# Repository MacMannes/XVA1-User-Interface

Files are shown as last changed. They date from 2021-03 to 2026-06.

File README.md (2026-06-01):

# XVA1 User Interface

A hardware user interface for the [XVA1 virtual analog synthesizer](https://www.futur3soundz.com/), inspired by the Hydrasynth's layout. The XVA1 (and its FM sibling the XFM2) is built on an Artix-7 FPGA but has no built-in UI — this project adds one.

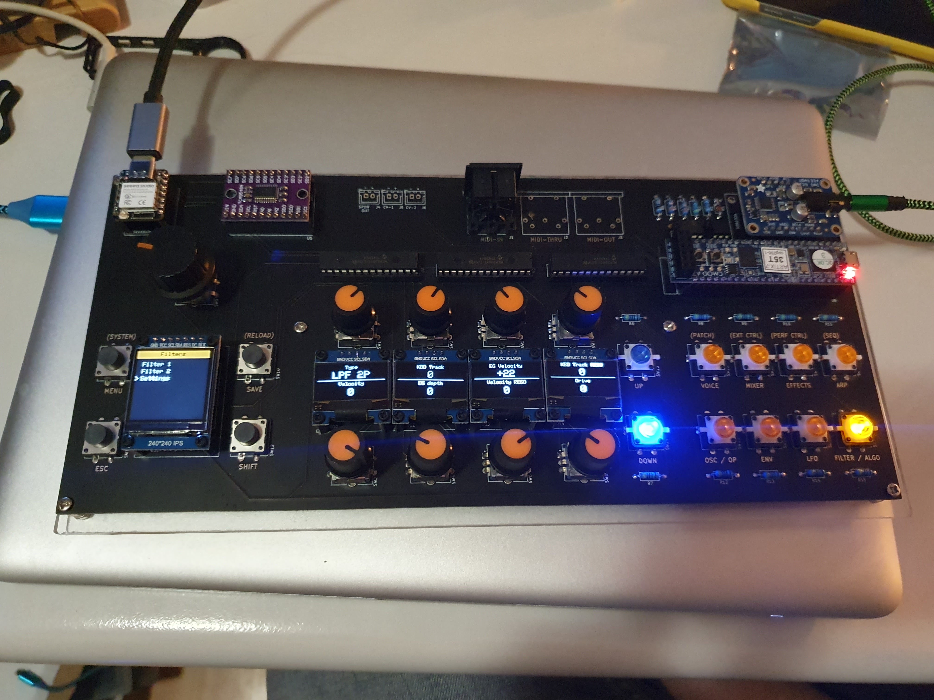
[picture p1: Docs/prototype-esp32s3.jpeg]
XVA1 User Interface prototype


## Overview

The UI board provides:

- **1 main rotary encoder** — patch selection and menu navigation
- **8 parameter rotary encoders** — control up to 8 synth parameters at once
- **4 OLED displays (128×64)** — show parameter names and values for each encoder pair
- **1 TFT display (240×240)** — main display showing patch name, section, and subsection
- **8 shortcut buttons with LEDs** — jump directly to parameter sections (Oscillators, Filters, Envelopes, LFOs, etc.). Hold SHIFT + buttons 1–4 to access sections 9–12
- **Up/Down buttons with LEDs** — scroll through parameter pages within a section

The design goal was minimal menu-diving: select a section with one button press, then tweak up to eight parameters directly with the encoders.

## Hardware

- **MCU:** Seeed XIAO ESP32-S3 (240 MHz, dual-core)
- **IO expansion:** 2× MCP23017 (the 8 parameter encoders connect via I2C)
- **Display mux:** TCA9548A I2C multiplexer for the 4 OLED displays
- **Synth connection:** UART at 500,000 baud (D6 TX, D7 RX)
- **PCB size:** 285 mm × 130 mm
- **Buttons:** PB86-B1 (with LED) / PB86-B0 (without LED), available from AliExpress

KiCad schematics are in the `Hardware/` directory.

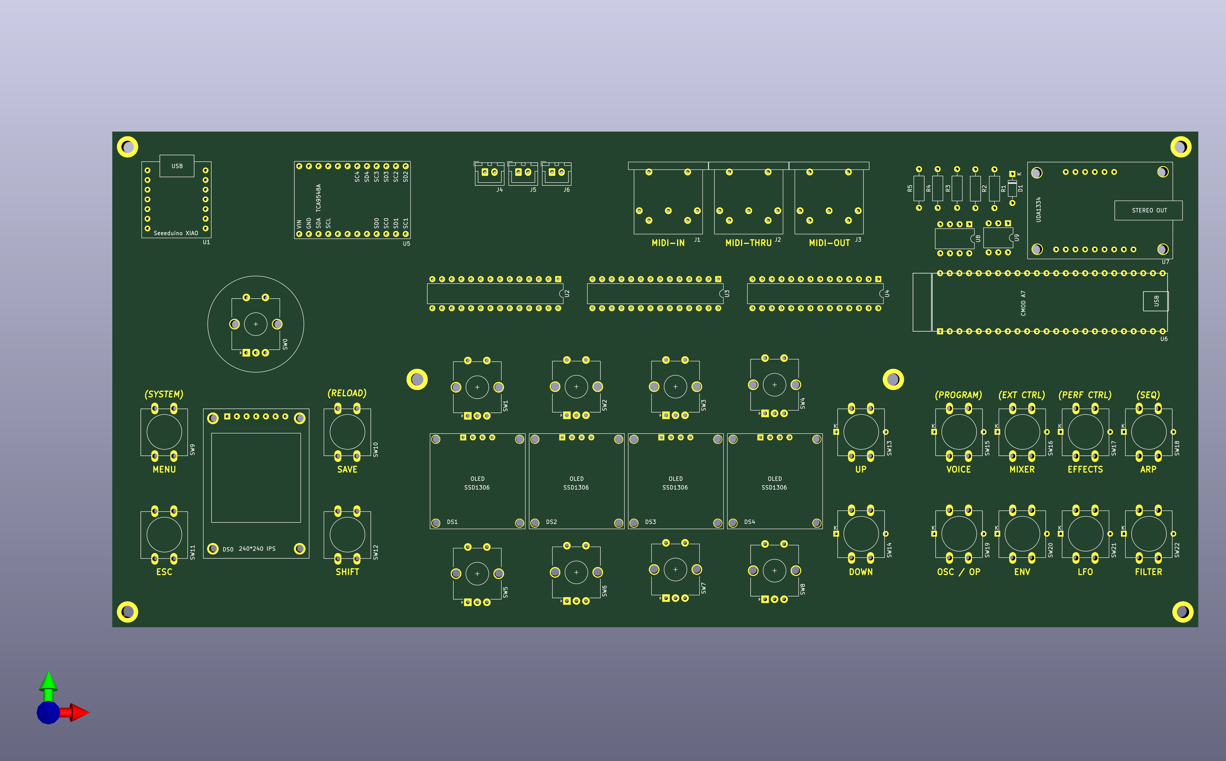
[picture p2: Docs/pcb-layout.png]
PCB layout


## Build History

The project started in early 2021 on a breadboard with a Seeeduino XIAO (SAMD21), then moved to an ESP32 devboard when memory became a bottleneck, and eventually settled on the **Seeed XIAO ESP32-S3** as a drop-in replacement with the same footprint. The first PCB prototype was ordered from JLCPCB and had a few minor errors (MIDI DIN pin swap, resistor silkscreen mix-up) that were corrected in subsequent revisions.

## Software

### UI Board Firmware

Firmware source is in `Software/XVA1UserInterface/` and built with [PlatformIO](https://platformio.org/).

```bash
# Run from Software/XVA1UserInterface/
platformio run                  # compile
platformio run -t upload        # compile and flash
platformio run -t monitor       # open serial monitor (115200 baud)
./upload_and_monitor.sh         # flash then monitor
```

See `AGENTS.md` for a full architecture breakdown and development notes.

### Use in Neovim

In order to use this project in Neovim, you will have to create the file `compile_commands.json`
file by running the following command:

```bash
pio run -t compiledb
```

### Synth Management

To manage the XVA1 (or XFM/XFM2) synthesizer's own firmware and programs, use [**xload-macos**](https://github.com/MacMannes/xload-macos) — a macOS tool for managing flash memory on XFM/XFM2/XVA1 synthesizers.

## Project Structure

```
Hardware/       KiCad schematics and datasheets
Docs/           Photos of front and back of the board
Software/
  XVA1UserInterface/   PlatformIO project (all firmware lives here)
```

## Status

Working prototype. Most parameters are implemented and editable. Patch saving is not yet implemented. The PCB design has gone through two revisions; the current version uses the XIAO ESP32-S3.

## License

See `LICENSE.md`.

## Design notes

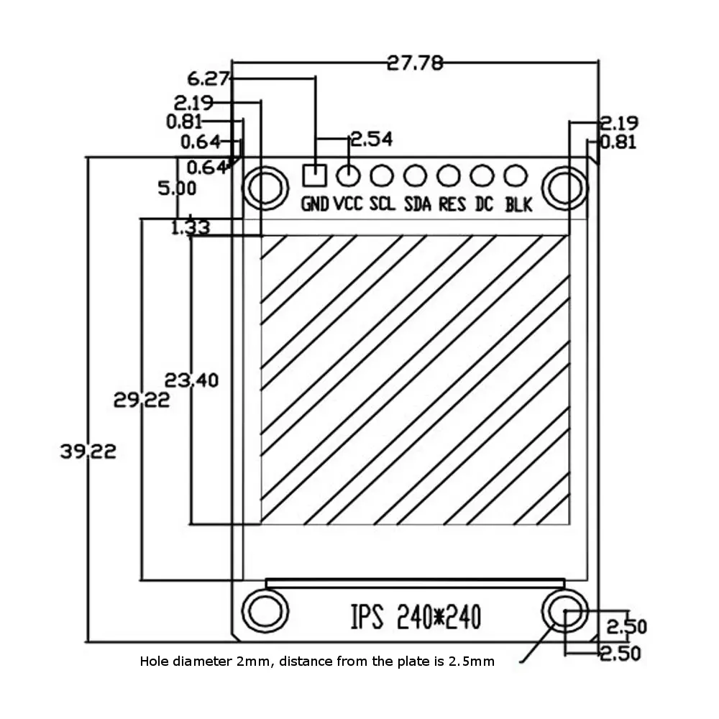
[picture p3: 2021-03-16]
Hardware/Datasheets/tft_st7789.jpg

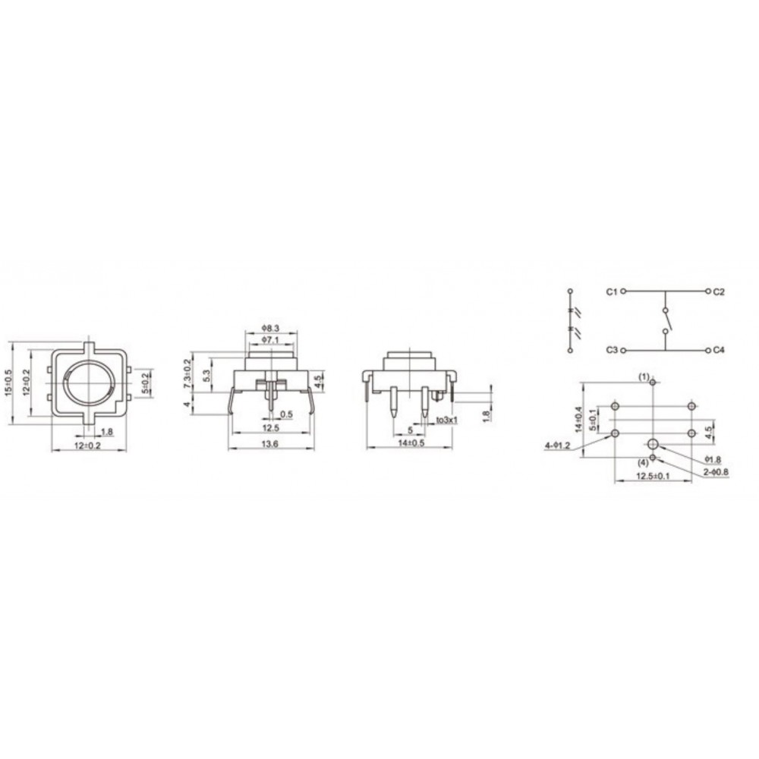
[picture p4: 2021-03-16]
Hardware/Datasheets/btn_led.jpg

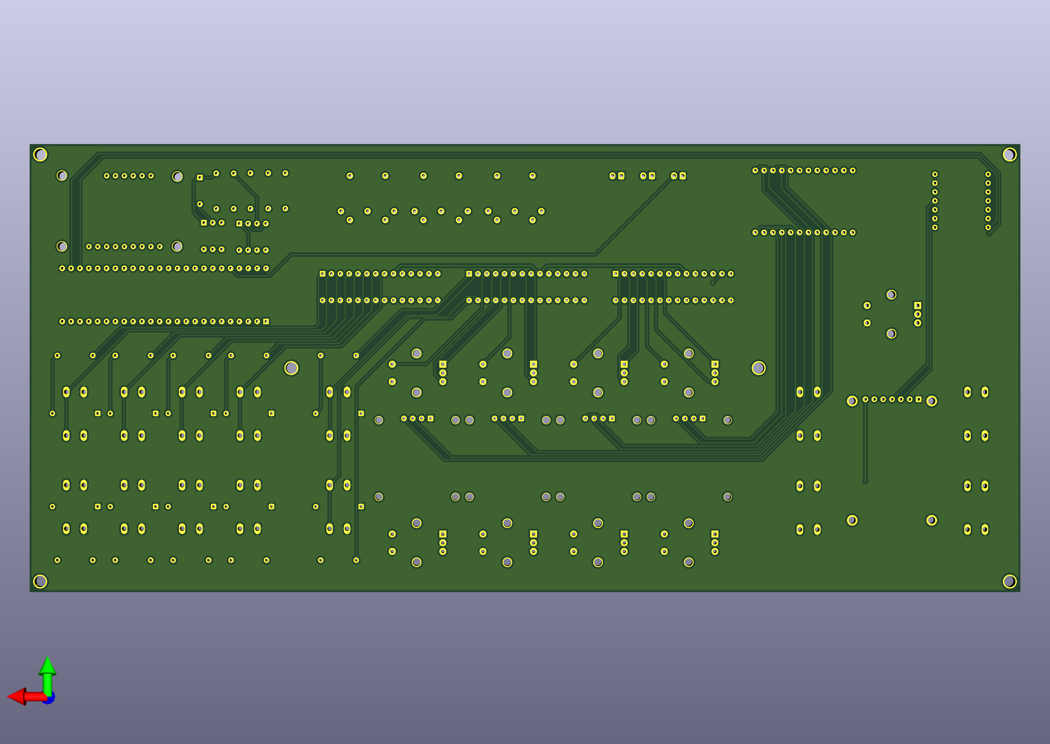
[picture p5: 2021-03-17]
Docs/xva1-ui-back.png

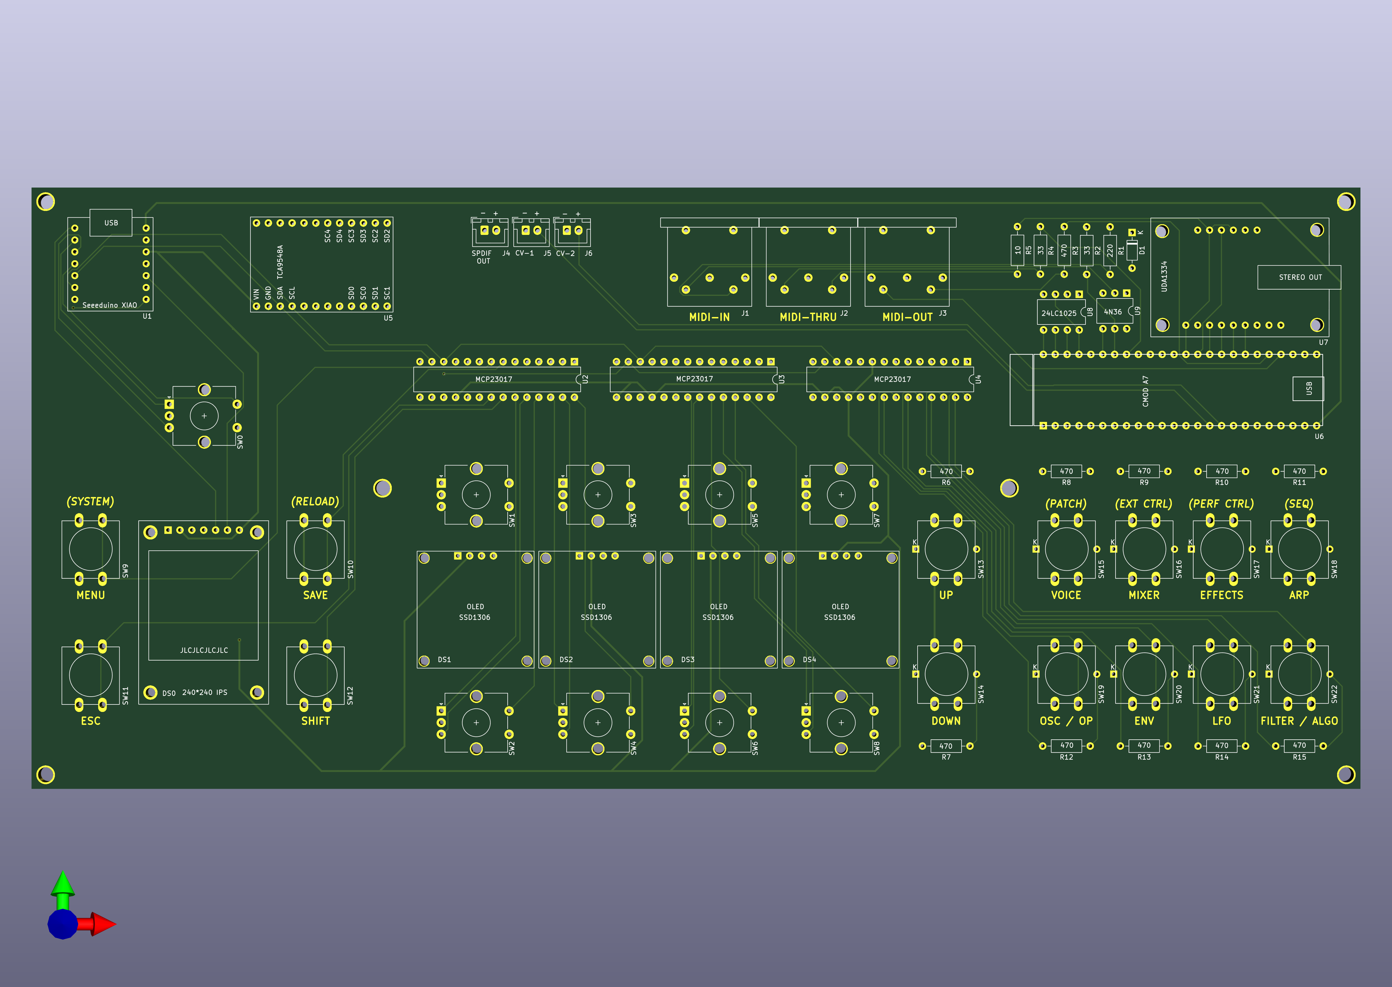
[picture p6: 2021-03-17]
Docs/xva1-ui-front.png

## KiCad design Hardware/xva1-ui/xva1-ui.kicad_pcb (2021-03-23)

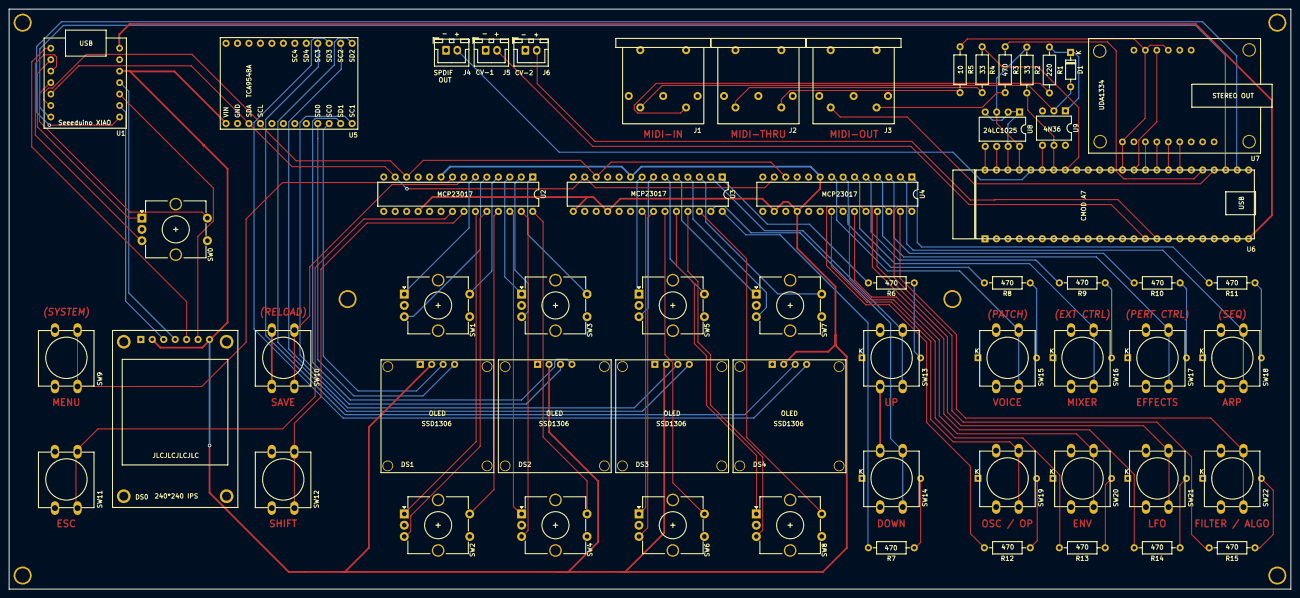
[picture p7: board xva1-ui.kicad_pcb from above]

Board: 2 copper layers, 284.0 x 128.5 mm, 59 parts (0 on the bottom side), 104 nets.

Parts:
D1: 1N4148; D_DO-35_SOD27_P7.62mm_Horizontal
DS0: TFT_ST7789; TFT_IPS-240_240
DS1, DS2, DS3, DS4: SSD1306
J1, J2, J3: DIN-5_180degree; MIDI_CONNECTOR_PCB
J4, J5, J6: Conn_01x02; JST_XH_B2B-XH-A_1x02_P2.50mm_Vertical
R1: 220; R_Axial_DIN0207_L6.3mm_D2.5mm_P10.16mm_Horizontal
R2, R6, R7, R8, R9, R10, R11, R12, R13, R14, R15: 470; R_Axial_DIN0207_L6.3mm_D2.5mm_P10.16mm_Horizontal
R3, R4: 33; R_Axial_DIN0207_L6.3mm_D2.5mm_P10.16mm_Horizontal
R5: 10; R_Axial_DIN0207_L6.3mm_D2.5mm_P10.16mm_Horizontal
SW0, SW1, SW2, SW3, SW4, SW5, SW6, SW7, SW8: Rotary Encoder; RotaryEncoder_Alps_EC12E-Switch_Vertical_H20mm_CircularMoun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
SW9, SW10, SW11, SW12: SW_Push; SW_PUSH-12mm
SW13, SW14, SW15, SW16, SW17, SW18, SW19, SW20, SW21, SW22: SW_Push_LED; SW_PUSH_LED-12mm
U1: Seeeduino XIAO; Seeduino_XIAO_Through-Hole
U2, U3, U4: MCP23017; DIP-28_W7.62mm
U5: TCA9548A; TCA9548A_BREAKOUT
U6: CMOD-A7; CMOD-A7-DIP-48_W15.24mm
U7: UDA1334
U8: 24LC1025-I/P; DIP-8_W7.62mm
U9: 4N36; DIP-6_W7.62mm

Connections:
+3V3: DS0.2, DS0.7, DS1.2, DS2.2, DS3.2, DS4.2, U1.12, U2.9, U2.18, U3.9, U3.15, U3.18, U4.9, U4.16, U4.18, U5.1
+5V: U1.14, U6.24
/BTN-ESC: SW11.2, U2.21
/BTN-MENU: SW9.2, U2.8
/BTN-SAVE: SW10.2, U2.7
/BTN-SHIFT: SW12.2, U2.22
/ENC-A: SW0.A, U1.2
/ENC-B: SW0.B, U1.3
/ENC-S: SW0.S1, U1.4
/SCL: U1.6, U2.12, U3.12, U4.12, U5.4
/SDA: U1.5, U2.13, U3.13, U4.13, U5.3
BTN-DWN: SW14.2, U3.27
BTN-SC1: SW15.2, U4.8
BTN-SC2: SW16.2, U4.6
BTN-SC3: SW17.2, U4.4
BTN-SC4: SW18.2, U4.2
BTN-SC5: SW19.2, U4.21
BTN-SC6: SW20.2, U4.23
BTN-SC7: SW21.2, U4.25
BTN-SC8: SW22.2, U4.27
BTN-UP: SW13.2, U3.2
CV-INPUT-1: J5.2, U6.15
CV-INPUT-2: J6.2, U6.16
ENC1-A: SW1.A, U2.6
ENC1-B: SW1.B, U2.5
ENC1-S: SW1.S1, U2.4
ENC2-A: SW2.A, U2.23
ENC2-B: SW2.B, U2.24
ENC2-S: SW2.S1, U2.25
ENC3-A: SW3.A, U2.3
ENC3-B: SW3.B, U2.2
ENC3-S: SW3.S1, U2.1
ENC4-A: SW4.A, U2.26
ENC4-B: SW4.B, U2.27
ENC4-S: SW4.S1, U2.28
ENC5-A: SW5.A, U3.8
ENC5-B: SW5.B, U3.7
ENC5-S: SW5.S1, U3.6
ENC6-A: SW6.A, U3.21
ENC6-B: SW6.B, U3.22
ENC6-S: SW6.S1, U3.23
ENC7-A: SW7.A, U3.5
ENC7-B: SW7.B, U3.4
ENC7-S: SW7.S1, U3.3
ENC8-A: SW8.A, U3.24
ENC8-B: SW8.B, U3.25
ENC8-S: SW8.S1, U3.26
GND: DS0.1, DS1.1, DS2.1, DS3.1, DS4.1, J4.1, J5.1, J6.1, SW0.C, SW0.S2, SW1.C, SW1.S2, SW2.C, SW2.S2, SW3.C, SW3.S2, SW4.C, SW4.S2, SW5.C, SW5.S2, SW6.C, SW6.S2, SW7.C, SW7.S2, SW8.C, SW8.S2, SW9.1, SW10.1, SW11.1, SW12.1, SW13.1, SW13.3, SW14.1, SW14.3, SW15.1, SW15.3, SW16.1, SW16.3, SW17.1, SW17.3, SW18.1, SW18.3, SW19.1, SW19.3, SW20.1, SW20.3, SW21.1, SW21.3, SW22.1, SW22.3, U1.13, U2.10, U2.15, U2.16, U2.17, U3.10, U3.16, U3.17, U4.10, U4.15, U4.17, U5.2, U6.25
LED-DWN: R7.2, U3.28
LED-SC1: R8.2, U4.7
LED-SC2: R9.2, U4.5
LED-SC3: R10.2, U4.3
LED-SC4: R11.2, U4.1
LED-SC5: R12.2, U4.22
LED-SC6: R13.2, U4.24
LED-SC7: R14.2, U4.26
LED-SC8: R15.2, U4.28
LED-UP: R6.2, U3.1
unnamed: D1.1, R1.1, U9.1
unnamed: D1.2, J1.5, U9.2
unnamed: DS0.3, U1.9
unnamed: DS0.4, U1.11
unnamed: DS0.5, U1.1
unnamed: DS0.6, U1.10
unnamed: J1.4, R1.2
unnamed: J2.4, R5.1
unnamed: J2.5, R4.1
unnamed: J3.4, R3.1
unnamed: J3.5, U6.28
unnamed: R2.1, U6.45, U8.3, U8.8
unnamed: R2.2, U6.42, U9.5
unnamed: R3.2, U6.29
unnamed: R4.2, U6.41
unnamed: R5.2, U6.36, U7.1, U7.12, U7.14
unnamed: R6.1, SW13.4
unnamed: R7.1, SW14.4
unnamed: R8.1, SW15.4
unnamed: R9.1, SW16.4
unnamed: R10.1, SW17.4
unnamed: R11.1, SW18.4
unnamed: R12.1, SW19.4
unnamed: R13.1, SW20.4
unnamed: R14.1, SW21.4
unnamed: R15.1, SW22.4
unnamed: U6.31, U7.6
unnamed: U6.32, U7.5
unnamed: U6.33, U7.4
unnamed: U6.34, U7.3
unnamed: U6.35, U7.13
unnamed: U6.43, U9.4
unnamed: U6.46, U8.1, U8.2, U8.4, U8.7
unnamed: U6.47, U8.6
unnamed: U6.48, U8.5
OLED1-SCL: DS1.3, U5.10
OLED1-SDA: DS1.4, U5.9
OLED2-SCL: DS2.3, U5.12
OLED2-SDA: DS2.4, U5.11
OLED3-SCL: DS3.3, U5.14
OLED3-SDA: DS3.4, U5.13
OLED4-SCL: DS4.3, U5.16
OLED4-SDA: DS4.4, U5.15
SPDIF-OUT: J4.2, U6.44
XIAO-RX: U1.8, U6.26
XIAO-TX: U1.7, U6.27

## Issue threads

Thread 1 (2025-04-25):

MIDI performance control bug

craigyjp, 2025-04-25:
I hope you don’t mind me mentioning a bug in your code when editing MIDI perf controls, these are supposed to be editable between 1-511 to cover all parameters of the synth, but your code only allows you to edit them from 0-255 due to using a byte rather than an integer for definition.

Currently you display 257 as a value for one of the MIDI performance controllers, but you cannot increment that, only decrement it, then once it is 255 it will not go any higher.

Also I added the range limit of 1-511 as 0 is not available as that is not a valid parameter in the synth.

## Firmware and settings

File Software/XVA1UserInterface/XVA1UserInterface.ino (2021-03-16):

/*
    XVA1 User Interface
*/

#include <SPI.h>
#include <TFT_eSPI.h>
#include <Wire.h>
#include <Adafruit_GFX.h>
#include <Adafruit_SSD1306.h>
#include <splash.h>
#include "RotaryEncOverMCP.h"
#include "Rotary.h"
#include "SynthParameter.h"

#define MUX_ADDRESS 0x70 // TCA9548A Multiplexer address

#define SCREEN_WIDTH 128 // OLED display width, in pixels
#define SCREEN_HEIGHT 64 // OLED display height, in pixels
#define LOGO_HEIGHT   16
#define LOGO_WIDTH    16

#define SHIFT_BTN_PIN 8
#define SHORTCUT_BTN1_PIN 9
#define SHORTCUT_LED1_PIN 10

#define ROTARY_BTN1_PIN 2
#define ROTARY_BTN2_PIN 5

int allButtons[] = { SHIFT_BTN_PIN, SHORTCUT_BTN1_PIN, ROTARY_BTN1_PIN, ROTARY_BTN2_PIN};
constexpr int numButtons = (int)(sizeof(allButtons) / sizeof(*allButtons));


/* First I2C MCP23017 GPIO expanders */
Adafruit_MCP23017 mcp1;  

//Array of pointers of all MCPs (for now, there's only 1)
Adafruit_MCP23017* allMCPs[] = { &mcp1 };
constexpr int numMCPs = (int)(sizeof(allMCPs) / sizeof(*allMCPs));

/* function prototypes */
void rotaryEncoderChanged(bool clockwise, int id);

/* Array of all rotary encoders and their pins */
RotaryEncOverMCP rotaryEncoders[] = {
        // outputA,B on GPA7,GPA6, register with callback and ID=1
        RotaryEncOverMCP(&mcp1, 7, 6, &rotaryEncoderChanged, 0),
        RotaryEncOverMCP(&mcp1, 1, 0, &rotaryEncoderChanged, 1),
        RotaryEncOverMCP(&mcp1, 4, 3, &rotaryEncoderChanged, 2)
};
constexpr int numEncoders = (int)(sizeof(rotaryEncoders) / sizeof(*rotaryEncoders));

// Initialize I2C buses using TCA9548A I2C Multiplexer
void selectMultiplexerChannel(uint8_t i2c_bus) {
    if (i2c_bus > 7) return;
    Wire.beginTransmission(MUX_ADDRESS);
    Wire.write(1 << i2c_bus);
    Wire.endTransmission(); 
}

// Declaration for an SSD1306 display connected to I2C (SDA, SCL pins)
#define OLED_RESET     -1 // Reset pin # (or -1 if sharing Arduino reset pin)
Adafruit_SSD1306 display(SCREEN_WIDTH, SCREEN_HEIGHT, &Wire, OLED_RESET);

const int MAX = 128;
const int MIN = 1;
int currentPatchNumber = MIN;
String currentPatchName = "";
byte currentPatchData[512];

TFT_eSPI tft = TFT_eSPI();  // Invoke library, pins defined in User_Setup.h

#define TFT_GREY 0x5AEB // New colour

struct SynthParameter param1;
struct SynthParameter param2;
struct SynthParameter param3;
struct SynthParameter param4;

unsigned long lastTransition;
unsigned long revolutionTime = 0;

bool shiftButtonPushed = false;
int shortcutButtonState = HIGH;
bool shortcut1Active = false;

void rotaryEncoderChanged(bool clockwise, int id) {
    unsigned long now = millis();
    revolutionTime = now - lastTransition;    

    int speed = 1;
    if (revolutionTime < 50) {
        speed = 20;
    } else if (revolutionTime < 125) {
        speed = 10;
    } else if (revolutionTime < 250) {
        speed = 2;
    } 

    lastTransition = now;
  
    Serial.println("Encoder " + String(id) + ": "
            + (clockwise ? String("clockwise") : String("counter-clock-wise")) + ", Speed: " + String(speed));
    if (id == 0) {
       handleMainEncoder(clockwise);
    }
    if (shiftButtonPushed) {
      if (id == 1) {
          handleParameterChange(&param3, clockwise, speed);
          displayTwinParameters(&param3, &param4, 1);
      }
      if (id == 2) {
          handleParameterChange(&param4, clockwise, speed);
          displayTwinParameters(&param3, &param4, 1);
      }
    } else {
      if (id == 1) {
          handleParameterChange(&param1, clockwise, speed);
          displayTwinParameters(&param1, &param2, 0);
      }
      if (id == 2) {
          handleParameterChange(&param2, clockwise, speed);
          displayTwinParameters(&param1, &param2, 0);
      }
    }
}


void setup() {
    SerialUSB.begin(115200);

     //while the serial stream is not open, do nothing:
//     while (!Serial);   

//    strcpy(param1.name, "FilterType");
//    param1.number = 71;
//    param1.min = 0;
//    param1.max = 21;
//    param1.descriptions[0] = "Bypass";
//    param1.descriptions[1] = "1P_LowPass";
//    param1.descriptions[2] = "2P_LowPass";
//    param1.descriptions[3] = "3P_LowPass";
//    param1.descriptions[4] = "4P_LowPass";
//    param1.descriptions[5] = "1P_HighPass";
//    param1.descriptions[6] = "2P_HighPass";
//    param1.descriptions[7] = "3P_HighPass";
//    param1.descriptions[8] = "4P_HighPass";


    strcpy(param1.name, "Sequencer");
    param1.number = 428;
    param1.min = 0;
    param1.max = 1;    
    param1.descriptions[0] = "OFF";
    param1.descriptions[1] = "ON";
    
    strcpy(param2.name, "Cutoff");
    param2.number = 72;
    param2.min = 0;
    param2.max = 255;

    strcpy(param3.name, "PerfCtl1");
    param3.type = PERFORMANCE_CTRL;
    param3.number = 400;
    param3.number2 = 401;
    param3.min = 0;
    param3.max = 511;

    strcpy(param4.name, "PerfCtl2");
    param4.type = PERFORMANCE_CTRL;
    param4.number = 402;
    param4.number2 = 403;   
    param4.min = 0;
    param4.max = 511;

//    strcpy(param1.name, "ARP_MODE");
//    param1.number = 450;
//    param1.min = 0;
//    param1.max = 5;    
//    strcpy(param2.name, "Octaves");
//    param2.number = 454;
//    param2.min = 0;
//    param2.max = 5;
    
  
    mcp1.begin();      // use default address 0
    // Initialize input encoders (pin mode, interrupt)
    for(int i=0; i < numEncoders; i++) {
        rotaryEncoders[i].init();
    }

    initOledDisplays();
    initButtons();
    
    Serial1.begin(500000); // XVA1 Serial
  
    tft.init();
    tft.setRotation(0);  // 0 & 2 Portrait. 1 & 3 landscapeooooooo;;
    tft.fillScreen(TFT_BLACK);
  
    tft.setCursor(0, 0, 2);
    // Set the font colour to be white with a black background, set text size multiplier to 1
    tft.setTextColor(TFT_WHITE,TFT_BLACK);  
    tft.setTextSize(1);
    tft.println("XVA1 Synthesizer");  
    
  
    
    SerialUSB.println("\n");
    SerialUSB.println("===================");
    SerialUSB.println("XVA1 User Interface");
    SerialUSB.println("===================\n");
    SerialUSB.print("value=");
    SerialUSB.println(currentPatchNumber);
  
    selectPatchOnSynth(currentPatchNumber);
    getPatchDataFromSynth();
    displayPatchInfo();

}

void loop() {
    pollAllMCPs();
    readButtons();    
}


void initOledDisplays() {
    for (int d = 0; d < 2; d++) {
      selectMultiplexerChannel(d);
      // SSD1306_SWITCHCAPVCC = generate display voltage from 3.3V internally
      display.begin(SSD1306_SWITCHCAPVCC, 0x3C);
    
      display.clearDisplay();
    }  
}

void initButtons() {
  for (int i = 0; i < numButtons; i++) {
      int pin = allButtons[i];
      mcp1.pinMode(pin, INPUT);   // Button i/p to GND
      mcp1.pullUp(pin, HIGH);     // Pulled high ~100k    
  }
  
//  mcp1.pinMode(SHIFT_BTN_PIN, INPUT);   // Button i/p to GND
//  mcp1.pullUp(SHIFT_BTN_PIN, HIGH);     // Pulled high ~100k


  mcp1.pinMode(SHORTCUT_LED1_PIN, OUTPUT);   // LED from Shortcut button 1
  
}

void readButtons() {
    bool shiftButton = mcp1.digitalRead(SHIFT_BTN_PIN) == LOW;
    if (shiftButton != shiftButtonPushed) {
      shiftButtonPushed = shiftButton;
      SerialUSB.print("Shift: ");
      SerialUSB.println(shiftButtonPushed);
    }
    

    int shortcutButton1 = mcp1.digitalRead(SHORTCUT_BTN1_PIN);
    if (shortcutButton1 != shortcutButtonState) {
      shortcutButtonState = shortcutButton1;
      SerialUSB.print("Shortcut 1: ");
      SerialUSB.println(shortcutButton1 == LOW);

      if (shortcutButton1 == HIGH) {
        // Button released, toggle LED        
        shortcut1Active = !shortcut1Active;
        mcp1.digitalWrite(SHORTCUT_LED1_PIN, shortcut1Active ? HIGH : LOW);
      }
    }
    
}

void handleMainEncoder(bool clockwise) {
    int oldValue = currentPatchNumber;

    if (clockwise) {
      if (currentPatchNumber < MAX) {
        currentPatchNumber++;
      }
    } else {
      if (currentPatchNumber > MIN) {
        currentPatchNumber--;
      }        
    }

    SerialUSB.print("Selecting patch: ");
    SerialUSB.println(currentPatchNumber);

    if (currentPatchNumber != oldValue) {
       selectPatchOnSynth(currentPatchNumber);
       getPatchDataFromSynth();
       displayPatchInfo();
    }
}

void selectPatchOnSynth(int patchNumber) {
    int synthPatchNumber = patchNumber - 1;
    
    SerialUSB.print("Selecting patch #");
    SerialUSB.print(synthPatchNumber);
    SerialUSB.print(" on Synth...");
    
    Serial1.write('r'); // 'r' = Read program
    Serial1.write(synthPatchNumber);
  
  
    int read_status;
    int bytesRead = 0;
    int retry = 0;
    while (bytesRead == 0 && retry != 100) {
      if (Serial1.available()) {
          read_status = Serial1.read();
          bytesRead++;
          retry = 0;
      } else {
        retry++;
        delay(10);
      }
    }  
  
    SerialUSB.print("Status=");
    SerialUSB.println(read_status, DEC);  

}

void getPatchDataFromSynth() {

    Serial1.write('d'); // 'd' = Display program

    SerialUSB.println("Reading patch data from Synth...");

    byte rxBuffer[512];
    int bytesRead = 0;
    int retry = 0;
    while (bytesRead != 512 && retry != 100) {
      if (Serial1.available()) {
          byte b = Serial1.read();
          rxBuffer[bytesRead] = b;
          bytesRead++;
          retry = 0;
      } else {
        retry++;
        delay(10);
      }
    }
    
//    for (int i = 0; i < sizeof(rxBuffer); i++){
//      printHex(rxBuffer[i]);
//    }
  
    SerialUSB.println();

    String patchName = "";
 
    for (int i=480; i<505; i++){
      patchName += (char)rxBuffer[i];
    }      

    SerialUSB.print("Patch name: ");
    SerialUSB.println(patchName);
    SerialUSB.println(); 
    
    Serial1.flush();

    memcpy(currentPatchData, rxBuffer, 512);
    currentPatchName = patchName; 
}

void displayPatchInfo() {
//  tft.setTextSize(2);
    tft.setTextColor(TFT_WHITE, TFT_BLACK);   
    tft.drawString("Patch", 0, 30, 1);
    
    tft.setTextColor(TFT_YELLOW, TFT_BLACK);   
  
    // Set the padding to the maximum width that the digits could occupy in font 4
    // This ensures small numbers obliterate large ones on the screen
    tft.setTextPadding(tft.textWidth("999", 4) );  
    // Draw the patch number in font 4
    tft.drawNumber(currentPatchNumber, 0, 42, 4);
  
    tft.setTextColor(TFT_RED, TFT_BLACK); 
  
    tft.setTextPadding(tft.textWidth("XXXXXXXXXXXXXXXXXXXXXXXXX", 2) );  
    // Draw the patch name in font 1
    tft.drawString(currentPatchName, 0, 75, 2);
  
    // Reset text padding to 0 otherwise all future rendered strings will use it!
    tft.setTextPadding(0);
  
    displayTwinParameters(&param1, &param2, 0);
    displayTwinParameters(&param3, &param4, 1);

}

void drawCenteredText(char *buf, int x, int y)
{
    int16_t x1, y1;
    uint16_t w, h;
    display.getTextBounds(buf, x, y, &x1, &y1, &w, &h); //calc width of new string
    display.setCursor(x - w / 2, y);
    display.print(buf);
}

void printHex(uint8_t num) {
    char hexCar[2];
  
    sprintf(hexCar, "%02X", num);
    SerialUSB.print(hexCar);
  }

void pollAllMCPs() {
    //We could also call ".poll()" on each encoder,
    //however that will cause an I2C transfer
    //for every encoder.
    //It's faster to only go through each MCP object,
    //read it, and then feed it into the encoder as input.
    for(int j = 0; j < numMCPs; j++) {
        uint16_t gpioAB = allMCPs[j]->readGPIOAB();
        for (int i=0; i < numEncoders; i++) {
            //only feed this in the encoder if this
            //is coming from the correct MCP
            if(rotaryEncoders[i].getMCP() == allMCPs[j])
                rotaryEncoders[i].feedInput(gpioAB);
        }
    }
}

void displayTwinParameters(SynthParameter *param1, SynthParameter *param2, int displayNumber) {  
    int byte1;
    int byte2;

    if (param1->type == PERFORMANCE_CTRL) {
      byte msb = currentPatchData[param1->number]; 
      byte lsb = currentPatchData[param1->number2]; 
      int combined = (msb << 7) + lsb;

      byte1 = (int)combined;      
    } else {
      byte1 = (int)currentPatchData[param1->number];      
    }    

    if (param2->type == PERFORMANCE_CTRL) {
      byte msb = currentPatchData[param2->number]; 
      byte lsb = currentPatchData[param2->number2]; 
      int combined = (msb << 7) + lsb;

      byte2 = (int)combined;      
    } else {
      byte2 = (int)currentPatchData[param2->number];      
    }    
    
    char printValue1[20];
    if (param1->type != PERFORMANCE_CTRL && byte1 < sizeof(param1->descriptions) && param1->descriptions[byte1] != nullptr) {
      strcpy(printValue1, param1->descriptions[byte1]);    
    } else {
      sprintf(printValue1,"%ld", byte1);
    }
    char printValue2[20];
    if (param2->type != PERFORMANCE_CTRL && byte2 < sizeof(param2->descriptions) && param2->descriptions[byte1] != nullptr) {
      strcpy(printValue2, param2->descriptions[byte2]);    
    } else {
      sprintf(printValue2,"%ld", byte2);
    }
  
    displayTwinParameters(param1->name, printValue1, param2->name, printValue2, displayNumber);
}

void displayTwinParameters(char *title1, char *value1, char *title2, char *value2, int displayNumber) {
    selectMultiplexerChannel(displayNumber);

    display.clearDisplay();  
    
    display.setTextSize(1);
    display.setTextColor(WHITE);
    drawCenteredText(title1, 64, 0);
  
    display.setTextSize(2);
    drawCenteredText(value1, 64, 12);
  
    display.drawLine(0, 30, display.width() - 1, 30, WHITE);
  
    
    display.setTextSize(1);
    drawCenteredText(title2, 64, 34);
  
    display.setTextSize(2);
    drawCenteredText(value2, 64, 47);
    
    display.display(); 
}

void handleParameterChange(SynthParameter *param, bool clockwise, int speed) {
    int currentValue;

    if (param->type == PERFORMANCE_CTRL) {
      byte msb = currentPatchData[param->number]; 
      byte lsb = currentPatchData[param->number2]; 
      int combined = (msb << 7) + lsb;
      currentValue = combined;
    } else {    
      currentValue = currentPatchData[param->number];
    }
    int newValue = -1;
  
    if (clockwise) {
        if (currentValue < param->max) {
            newValue = currentValue + speed;
            if  (newValue > param->max) {
                newValue = param->max;
            }
        }
    } else {
        if (currentValue > param->min) {
          newValue = currentValue - speed;
            if  (newValue < param->min) {
                newValue = param->min;
            }
        }
    }

  
    if (newValue >= 0 && newValue != currentValue) {
        SerialUSB.print("New value: ");
        SerialUSB.println(newValue);
        if (param->type == PERFORMANCE_CTRL) {
          byte msb = newValue >> 7;
          byte lsb = newValue & 127;

          currentPatchData[param->number] = msb;
          currentPatchData[param->number2] = lsb;

          setParameter(param->number, msb);
          setParameter(param->number2, lsb);          
        } else {
          currentPatchData[param->number] = newValue;
    
          setParameter(param->number, newValue);
        }
    }
  
}


void setParameter(int param, int value) {
    Serial1.write('s'); // 's' = Set Parameter

    if (param > 255) {
        // Parameters above 255 have a two-byte format: b1 = 255, b2 = x-256
        Serial1.write(255);
        Serial1.write(param - 256 );
        Serial1.write(value);
    } else {
        Serial1.write(param);
        Serial1.write(value);
    }
}

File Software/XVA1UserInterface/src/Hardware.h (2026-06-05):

//
// Created by André Mathlener on 05/04/2021.
//

#ifndef XVA1USERINTERFACE_HARDWARE_H
#define XVA1USERINTERFACE_HARDWARE_H

#include <Rotary.h>
#include <RotaryEncOverMCP.h>

#include "Button.h"
#include "Multiplexer.h"
#include "ParameterController.h"
#include "Synthesizer.h"

#define MAIN_ROTARY_BUTTON 0
#define MENU_BUTTON        1
#define SAVE_BUTTON        2
#define ESC_BUTTON         3
#define SHIFT_BUTTON       4

#define UP_BUTTON   1
#define DOWN_BUTTON 2

#define SCREEN_WIDTH  128  // OLED display width, in pixels
#define SCREEN_HEIGHT 64   // OLED display height, in pixels

// Declaration for an SSD1306 display connected to I2C (SDA, SCL pins)
#define OLED_RESET (-1)  // Reset pin # (or -1 if sharing Arduino reset pin)

#define MAIN_ROTARY_BTN_PIN D3

// Pins for MCP23017
#define GPA0 0
#define GPA1 1
#define GPA2 2
#define GPA3 3
#define GPA4 4
#define GPA5 5
#define GPA6 6
#define GPA7 7
#define GPB0 8
#define GPB1 9
#define GPB2 10
#define GPB3 11
#define GPB4 12
#define GPB5 13
#define GPB6 14
#define GPB7 15

/* Function prototypes */

void mainRotaryButtonChanged(bool released);

void mainButtonChanged(Button* btn, bool released);

void shortcutButtonChanged(Button* btn, bool released);

void rotaryButtonChanged(Button* btn, bool released);

void upOrDownButtonChanged(Button* btn, bool released);

void rotaryEncoderChanged(bool clockwise, int id);

// TCA9548A Multiplexer
Multiplexer multiplexer = Multiplexer(0x70);

// I2C MCP23017 GPIO expanders
Adafruit_MCP23017 mcp1;
Adafruit_MCP23017 mcp2;
Adafruit_MCP23017 mcp3;

// Array of pointers of all MCPs
Adafruit_MCP23017* allMCPs [] = { &mcp1, &mcp2, &mcp3 };

// OLED display
Adafruit_SSD1306 display(SCREEN_WIDTH, SCREEN_HEIGHT, &Wire, OLED_RESET);

// TFT display
TFT_eSPI tft = TFT_eSPI();  // Invoke library, pins defined in User_Setup.h

Rotary mainRotaryEncoder = Rotary(D1, D2);

/* Array of all rotary encoders and their pins */
RotaryEncOverMCP rotaryEncoders [] = {
    // outputA,B on GPA7,GPA6, register with callback and ID=1
    RotaryEncOverMCP(&mcp1, GPB5, GPB4, &rotaryEncoderChanged, 1),
    RotaryEncOverMCP(&mcp1, GPA2, GPA3, &rotaryEncoderChanged, 2),
    RotaryEncOverMCP(&mcp1, GPB2, GPB1, &rotaryEncoderChanged, 3),
    RotaryEncOverMCP(&mcp1, GPA5, GPA6, &rotaryEncoderChanged, 4),
    RotaryEncOverMCP(&mcp2, GPB7, GPB6, &rotaryEncoderChanged, 5),
    RotaryEncOverMCP(&mcp2, GPA0, GPA1, &rotaryEncoderChanged, 6),
    RotaryEncOverMCP(&mcp2, GPB4, GPB3, &rotaryEncoderChanged, 7),
    RotaryEncOverMCP(&mcp2, GPA3, GPA4, &rotaryEncoderChanged, 8),
};

Button menuButton = Button(&mcp1, GPB7, MENU_BUTTON, &mainButtonChanged);
Button saveButton = Button(&mcp1, GPB6, SAVE_BUTTON, &mainButtonChanged);
Button escButton = Button(&mcp1, GPA0, ESC_BUTTON, &mainButtonChanged);
Button shiftButton = Button(&mcp1, GPA1, SHIFT_BUTTON, &mainButtonChanged);

Button* mainButtons [] = {
    &menuButton,
    &saveButton,
    &escButton,
    &shiftButton,
};

LEDButton shortcutButton1 =
    LEDButton(&mcp3, GPB7, GPB6, 1, &shortcutButtonChanged);
LEDButton shortcutButton2 =
    LEDButton(&mcp3, GPB5, GPB4, 2, &shortcutButtonChanged);
LEDButton shortcutButton3 =
    LEDButton(&mcp3, GPB3, GPB2, 3, &shortcutButtonChanged);
LEDButton shortcutButton4 =
    LEDButton(&mcp3, GPB1, GPB0, 4, &shortcutButtonChanged);
LEDButton shortcutButton5 =
    LEDButton(&mcp3, GPA0, GPA1, 5, &shortcutButtonChanged);
LEDButton shortcutButton6 =
    LEDButton(&mcp3, GPA2, GPA3, 6, &shortcutButtonChanged);
LEDButton shortcutButton7 =
    LEDButton(&mcp3, GPA4, GPA5, 7, &shortcutButtonChanged);
LEDButton shortcutButton8 =
    LEDButton(&mcp3, GPA6, GPA7, 8, &shortcutButtonChanged);

LEDButton* shortcutButtons [] = { &shortcutButton1, &shortcutButton2,
                                  &shortcutButton3, &shortcutButton4,
                                  &shortcutButton5, &shortcutButton6,
                                  &shortcutButton7, &shortcutButton8 };

Button rotaryButton1 = Button(&mcp1, GPB3, 1, &rotaryButtonChanged);
Button rotaryButton2 = Button(&mcp1, GPA4, 2, &rotaryButtonChanged);
Button rotaryButton3 = Button(&mcp1, GPB0, 3, &rotaryButtonChanged);
Button rotaryButton4 = Button(&mcp1, GPA7, 4, &rotaryButtonChanged);
Button rotaryButton5 = Button(&mcp2, GPB5, 5, &rotaryButtonChanged);
Button rotaryButton6 = Button(&mcp2, GPA2, 6, &rotaryButtonChanged);
Button rotaryButton7 = Button(&mcp2, GPB2, 7, &rotaryButtonChanged);
Button rotaryButton8 = Button(&mcp2, GPA5, 8, &rotaryButtonChanged);

LEDButton upButton = LEDButton(&mcp2, GPB1, GPB0, 1, &upOrDownButtonChanged);
LEDButton downButton = LEDButton(&mcp2, GPA6, GPA7, 2, &upOrDownButtonChanged);
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

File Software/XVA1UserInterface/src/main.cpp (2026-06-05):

#include <Adafruit_I2CDevice.h>
#include <Adafruit_SSD1306.h>
#include <Arduino.h>
#include <TFT_eSPI.h>
#include <Wire.h>

#include "Button.h"
#include "Debug.h"
#include "FreeMemory.h"
#include "Globals.h"
#include "Hardware.h"
#include "SynthParameter.h"

unsigned long lastTransition;
unsigned long revolutionTime = 0;

int activeShortcut = 0;

bool shiftButtonPushed = false;
bool mainRotaryButtonPushed = false;

/* function prototypes */

void handleMainEncoder(bool clockwise);

void initOLEDDisplays();

void pollAllMCPs();

void readButtons();

void displayPatchInfo();

void displayPatchInfo(bool paintItBlack);

void initButtons();

void clearShortcut();

void clearMainScreen();

void initMainScreen();

void initRotaryEncoders();

void rtrim(std::string& s, char c);

void setup() {
    LOG_BEGIN();

    LOGLN("\n");
    LOGLN("===================");
    LOGLN("XVA1 User Interface");
    LOGLN("===================\n");

    mcp1.begin(0);
    mcp2.begin(1);
    mcp3.begin(2);

    synthesizer.begin();

    initMainScreen();
    clearMainScreen();

    initRotaryEncoders();
    initOLEDDisplays();
    initButtons();

    synthesizer.selectPatch(4);
    parameterController.setDefaultSection();
    displayPatchInfo();

    mainRotaryEncoder.begin(true);

    LOG("freeMemory()=");
    LOGLN(freeMemory());
}

void loop() {
    unsigned char result = mainRotaryEncoder.process();
    if (result) {
        bool clockwise = result == DIR_CW;
        if (activeShortcut != 0) {
            bool consumed =
                parameterController.rotaryEncoderChanged(0, clockwise, 1);
            if (!consumed) {
                handleMainEncoder(clockwise);
            }
        } else {
            handleMainEncoder(clockwise);
        }
    }

    readButtons();
    pollAllMCPs();
}

void rotaryEncoderChanged(bool clockwise, int id) {
    unsigned long now = millis();
    revolutionTime = now - lastTransition;

    int speed = 1;
    if (revolutionTime < 50) {
        speed = 20;
    } else if (revolutionTime < 125) {
        speed = 10;
    } else if (revolutionTime < 250) {
        speed = 2;
    }

    lastTransition = now;

    LOGLN(
        "Encoder " + String(id) + ": " +
        (clockwise ? String("clockwise") : String("counter-clock-wise")) +
        ", Speed: " + String(speed)
    );

    parameterController.rotaryEncoderChanged(id, clockwise, speed);
}

void initRotaryEncoders() {
    for (auto& rotaryEncoder : rotaryEncoders) {
        rotaryEncoder.init();
    }
}

void initMainScreen() {
    tft.init();
    tft.setRotation(0);  // 0 & 2 Portrait. 1 & 3 landscape;
}

void initOLEDDisplays() {
    for (int d = 0; d < 4; d++) {
        multiplexer.selectChannel(d);
        // SSD1306_SWITCHCAPVCC = generate display voltage from 3.3V internally
        display.begin(SSD1306_SWITCHCAPVCC, 0x3C);

        display.setTextWrap(false);
        display.clearDisplay();
        display.display();
    }
}

void initButtons() {
    for (auto& button : allButtons) {
        button->begin();
    }

    pinMode(MAIN_ROTARY_BTN_PIN, INPUT_PULLUP);
}

void readButtons() {
    bool mainRotaryButtonState = (digitalRead(MAIN_ROTARY_BTN_PIN) == LOW);
    if (mainRotaryButtonState != mainRotaryButtonPushed) {
        mainRotaryButtonPushed = mainRotaryButtonState;
        mainRotaryButtonChanged(!mainRotaryButtonPushed);
    }
}

void handleMainEncoder(bool clockwise) {
    int currentPatchNumber = synthesizer.getPatchNumber();
    int oldValue = currentPatchNumber;

    if (clockwise) {
        if (currentPatchNumber < 128) {
            currentPatchNumber++;
        }
    } else {
        if (currentPatchNumber > 1) {
            currentPatchNumber--;
        }
    }

    LOG("Selecting patch: ");
    LOGLN(currentPatchNumber);

    if (currentPatchNumber != oldValue) {
        synthesizer.selectPatch(currentPatchNumber);
        clearShortcut();
        parameterController.setDefaultSection();
        displayPatchInfo();
    }
}

void displayPatchInfo() {
    displayPatchInfo(false);
}

void rtrim(std::string& s, char c) {
    if (s.empty()) return;

    std::string::iterator p;
    for (p = s.end(); p != s.begin() && *--p == c;);

    if (*p != c) p++;

    s.erase(p, s.end());
}

void displayPatchInfo(bool paintItBlack) {
    int currentPatchNumber = synthesizer.getPatchNumber();

    tft.setTextColor(paintItBlack ? MY_ORANGE : TFT_BLACK);

    tft.setTextSize(2);
    tft.setTextDatum(1);
    tft.drawString("XVA1 Synthesizer", 119, 4, 1);

    tft.setTextColor((paintItBlack) ? TFT_BLACK : TFT_GREY);
    tft.drawString("Patch", 119, 40, 1);

    if (!paintItBlack) {
        tft.setTextColor(MY_ORANGE, TFT_BLACK);
    }

    // Set the padding to the maximum width that the digits could occupy in font
    // 4 This ensures small numbers obliterate large ones on the screen
    tft.setTextPadding(tft.textWidth("999", 4));
    // Draw the patch number in font 4
    tft.drawNumber(currentPatchNumber, 119, 65, 4);

    if (!paintItBlack) {
        tft.setTextColor(TFT_WHITE, TFT_BLACK);
    }

    tft.setTextPadding(tft.textWidth("XXXXXXXXXXXXXXXXXXXXXXXXX", 1));
    // Draw the patch name in font 1
    string name = synthesizer.getPatchName();
    rtrim(name, ' ');
    tft.drawString(name.c_str(), 119, 120, 1);

    // Reset text padding and datum to 0 otherwise all future rendered strings
    // will use it!
    tft.setTextPadding(0);
    tft.setTextDatum(0);
}

void clearMainScreen() {
    tft.fillScreen(TFT_BLACK);
    tft.fillRect(0, 0, 240, 26, MY_ORANGE);
}

void pollAllMCPs() {
    // Read all MCPs and feed the input to each encoder and shortcut button.
    // This is more efficient than reading one pin state at a time
    for (auto& mcp : allMCPs) {
        uint16_t gpioAB = mcp->readGPIOAB();

        for (auto& rotaryEncoder : rotaryEncoders) {
            // Only feed this in the encoder if this is coming from the correct
            // MCP
            if (rotaryEncoder.getMCP() == mcp) {
                rotaryEncoder.feedInput(gpioAB);
            }
        }

        for (auto& button : allButtons) {
            if (button->getMcp() == mcp) {
                button->feedInput(gpioAB);
            }
        }
    }
}

void shortcutButtonChanged(Button* btn, bool released) {
    LOG("Shortcut-button #");
    LOG(btn->id);
    LOG(" ");
    LOGLN((released) ? "RELEASED" : "PRESSED");

    if (!released) {
        if (activeShortcut > 0) {
            parameterController.clearScreen();
        }

        activeShortcut =
            (shiftButtonPushed && btn->id <= 4) ? btn->id + 8 : btn->id;

        LOG("Active Shortcut: ");
        LOGLN(activeShortcut);
        for (auto& shortcutButton : shortcutButtons) {
            shortcutButton->setLED(shortcutButton->id == btn->id);
        }

        displayPatchInfo(true);

        parameterController.setSection(activeShortcut);
    }
}
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

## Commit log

2021-02-15 Use rotary encoders with MCP23017
2021-02-17 Reformatting + added simple acceleraton for parameter encoders
2021-02-26 Implemented multiple oled diplays via TCA9548 i2c mux
2021-03-16 Added ShortcutButton1 (with LED) to prototype
    [XVA1UserInterface.ino]
2021-03-16 Refactoring: Moved code to Software + Added Hardware
    [xva1-ui-parameter-encoders.sch, xva1-ui.kicad_pcb, xva1-ui.sch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]
2021-03-16 Added resistors to LED buttons
    [xva1-ui-parameter-encoders.sch]
2021-03-16 Updated PCB layout + Added Gerber files
    [xva1-ui-parameter-encoders.sch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]
2021-03-17 Changed mounting holes + board outline
    [xva1-ui-B_Cu.gbr, xva1-ui-B_Mask.gbr, xva1-ui-B_SilkS.gbr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]
2021-03-23 Lock mounting holes
    [xva1-ui.kicad_pcb]
2021-03-24 Added LEDButton class
2021-04-01 Implemented shortcut-button handling
2021-04-02 Added Button class + created instances for all buttons
2021-04-03 Oops: switched PRESSED and RELEASED
2021-04-03 Pin A and Pin B of the rotary encoder were switched
2021-04-03 Added Up, Down and Main Rotary buttons
2021-04-08 Use pin names in stead of numbers + added all rotary encoders
2021-04-10 Fix for parameter value descriptions that were too big
    [main.cpp]
2021-04-23 Switched to esp32
2021-04-30 Switched Rate and Level pages of Envelope section + small changes
2021-05-01 Change type of Pitch envelope levels
2021-05-04 Use interrupts for main rotary encoder + button
2023-08-04 Revert "Use interrupts for main rotary encoder + button"
    This reverts commit 3dcfe536afd948128d9f93f24c43c69807b91256.
    [Hardware.h, main.cpp]
2023-08-06 Changed board to Seeed Studio XIAO ESP32S3
2026-05-30 fix: move SynthSerial from UART0 to UART1 to eliminate conflict with Serial
    SynthSerial was instantiated on UART0 (HardwareSerial(0)), the same
    peripheral used by Serial for debug output. This caused both to stomp
    over each other during synth communication.
    Fixed by:
    - Changing SynthSerial to UART1 (HardwareSerial(1))
    - Explicitly passing GPIO43 (D6/TX) and GPIO44 (D7/RX) in begin(),
    since -1/-1 would fall back to UART1's default pins, not D6/D7
    The ESP32-S3 GPIO matrix allows UART1 to be freely routed to any pins,
    so the physical wiring to the XVA1 is unchanged.
    Updated AGENTS.md to reflect that the conflict is resolved.
    [Synthesizer.cpp]
2026-05-30 refactor: replace Serial debug calls with compile-time LOG macros; enable USB CDC
    Introduce src/Debug.h with LOG/LOGLN/LOG_BEGIN macros that forward to
    Serial when -D DEBUG is set, and expand to nothing in production builds.
    All 53 raw Serial.print/println calls across main.cpp, Synthesizer.cpp
    and ParameterController.cpp are replaced with these macros.
    platformio.ini changes:
    - Add -D ARDUINO_USB_CDC_ON_BOOT=1: Serial becomes USB CDC on the
    XIAO ESP32-S3's native USB port, using no UART at all. This fully
    decouples debug output from the UART peripherals.
    - Add -D DEBUG: logging is on by default for development. Remove this
    flag for production builds to get zero debug overhead.
    Remov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
    [Synthesizer.cpp, main.cpp]
2026-05-31 fix: flush UART TX buffer after setParameter to prevent command misalignment
    Several parameter numbers coincide with destructive synth command bytes
    (116 = 't' tuning write, 86 = 'V' wavetable erase, 125 = '}' EEPROM
    write). If rapid back-to-back calls overflow the synth's UART FIFO and
    the leading 's' byte is dropped, the parameter number is interpreted as
    a command, corrupting flash.
    SynthSerial.flush() blocks until all bytes are physically sent (~60 µs
    at 500 kbps) before returning, ensuring the synth has processed each
    command before the next one arrives.
    Fixes #7
    [Synthesizer.cpp]
2026-05-31 fix: pin espressif32 platform to 6.3.2 for TFT_eSPI compatibility
    Arduino ESP32 3.x (platform 6.10.0+) has incompatibility with TFT_eSPI 2.5.43
    on ESP32-S3, causing SPI initialization failure at boot. Pinning to 6.3.2
    (Arduino ESP32 2.x) resolves the issue.
    Also includes prior fixes:
    - Increased displayEnvelopesTask stack size from 1000 to 4096 words
    - Added guard to prevent multiple concurrent envelope rendering tasks
    - Re-enabled ARDUINO_USB_CDC_ON_BOOT=1 (now works correctly with 2.x)
2026-05-31 docs: add detailed espressif32 platform upgrade guide
    - Explain why currently pinned to 6.3.2
    - Provide upgrade path when TFT_eSPI adds ESP32 3.x support
    - Document testing and rollback procedures
    - List alternative libraries (LovyanGFX) if needed
    - Add monitoring resources for library updates
2026-06-01 fix: clamp PERFORMANCE_CTRL values to 0-511 range
    MIDI performance controls should allow values 0-511 to cover all
    parameters of the XVA1 synth. Previously limited to 0-255 due to
    the generic uint8_t min/max clamping logic.
    Fixes #1
